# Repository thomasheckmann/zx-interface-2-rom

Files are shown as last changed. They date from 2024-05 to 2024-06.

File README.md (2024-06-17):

# ZX Interface 2 custom multi ROM catridge
Another custom ROM cartridge for ZX Interface 2, supporting 256kb EPROM with manual ROM selection using switch. The 256kb EPROM can hold up to 4 16kb banks, which is selectable with a switch combination.
This cartridge only supports 16KB images and manual bank switch and no paging out - it behaves just as the original ROM catridges.

## Schema and PCB version 1
Just a simple schema created with KiCad from description of original Interface 2 and Roms as found on the internet.

| SCHEMA | PCB |
| --- | --- |
|||

Assembled the cartridge looks like this



## PCB version 1.1
Even that the first version of the PBC works ok, a few errors was made - but again I'm new to KiCad, so I'm slowly learning :-)

- Most important error is that I forgot to check the pads, I simply forgot to check that the pads are added to the solder mask layer! So as can be seen on the image, I had to carefully scrabe the surface - for the pads to be visible.

- The switch are "mirrored" in my oppinion, I would expect the left switch to be the most significant bit (MSB) - so another change for next version.

- Slot in connector turned out to be a bit too narrow, so I had to make it a bit wider.

- If you look closely vias are placed between the connector pads, in next version that will be avoided - by adding safe zones between all pads.

- Resistor value changed from 4K7 to 10K, suggested as the EEPROM is CMOS and not TTL.

- EEPROM rotated so it has same orientation as the other IC (stupid yes, but important to some like me)

- Changed PCB from 4 to 2 layers (Only used 4 to reduces the number of vias created between pads)

With these changes version 1.1 of this little PCB ends up like this:

| <!---> | <!---> |
| --- | --- |
|||

And here how it looks like when build and attached to a ZX Spectrum

| <!---> | <!---> |
| --- | --- |
|||

## How to create image for EEPROM
The W27C512 EEPROM can contain 4 x 16Kb images - selectable with the switch, forming the binary number 0-3 of the bank active.

For Windows
```
COPY /B ROM_3+ROM_2+ROM_1+ROM_0 IMAGE.BIN
```
Use your favorite (E)EPROM programmer to transfer the IMAGE.BIN to the EEPROM

```
LEFT|RIGHT
OFF | OFF - 0: ROM_0
OFF | ON  - 1: ROM_1
ON  | OFF - 2: ROM_2
ON  | ON  - 3: ROM_3
```
## PCB version 1.2
Only small changes to v1.2 of the board, which I think now can be considered final.

- Changed from pull-ups to pull-downs, to match actual behaviour of DIP-SWITCH (up = 1/ON/HIGH, down = 0/OFF/LOW)
- Made PADS 2mm longer, as some connectors might have issues with the smaller size

| SCHEMA | PCB |
| --- | --- |
|||

## How to create image for EEPROM
The W27C512 EEPROM can contain 4 x 16Kb images - selectable with the switch, forming the binary number 0-3 of the bank active.

For Windows
```
COPY /B ROM_0+ROM_1+ROM_2+ROM_3 IMAGE.BIN
```
Use your favorite (E)EPROM programmer to transfer the IMAGE.BIN to the EEPROM
```
LEFT|RIGHT
OFF | OFF - 0: ROM_0
OFF | ON  - 1: ROM_1
ON  | OFF - 2: ROM_2
ON  | ON  - 3: ROM_3
```

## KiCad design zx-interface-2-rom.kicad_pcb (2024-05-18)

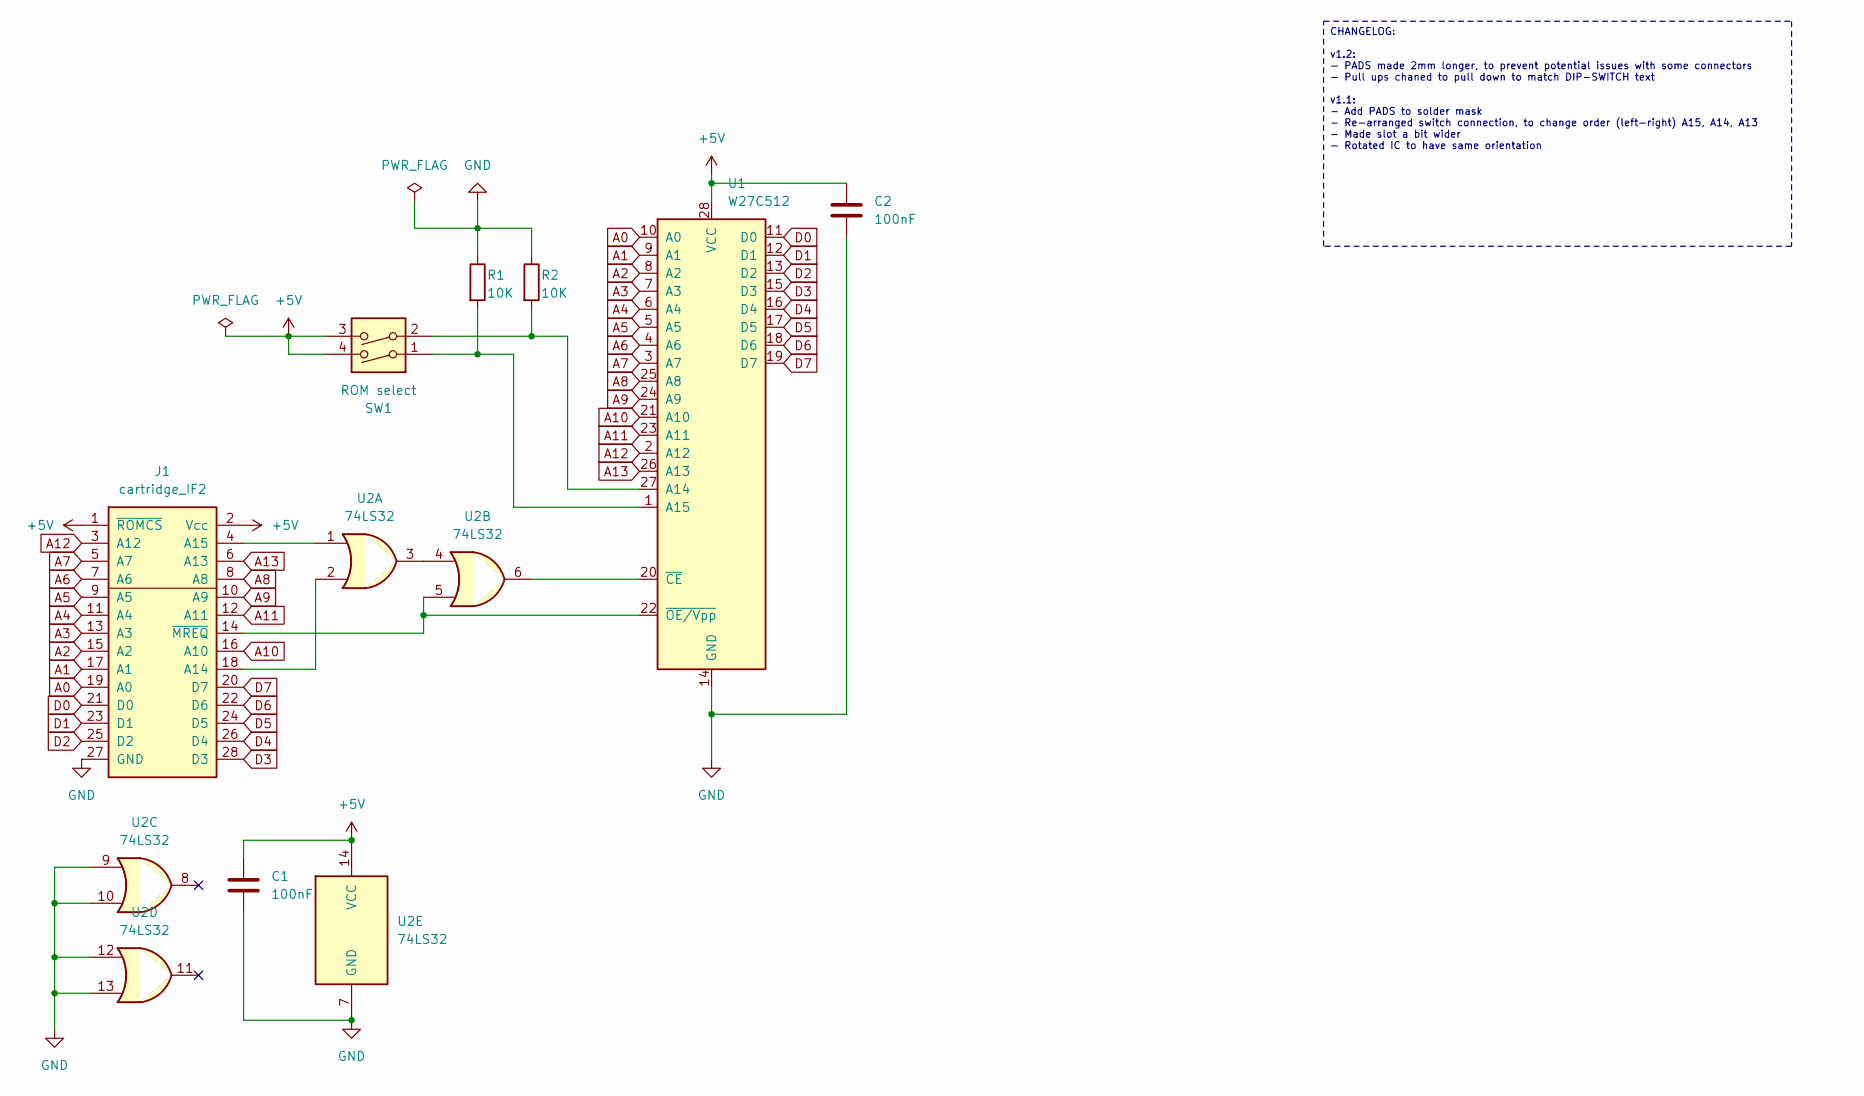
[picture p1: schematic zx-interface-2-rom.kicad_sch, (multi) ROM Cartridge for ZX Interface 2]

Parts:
C1, C2: 100nF; C_Disc_D3.0mm_W1.6mm_P2.50mm
J1: cartridge_IF2; CART_IF2_EDGE
R1, R2: 10K; R_Axial_DIN0207_L6.3mm_D2.5mm_P10.16mm_Horizontal
SW1: ROM select; SW_DIP_SPSTx02_Slide_6.7x6.64mm_W7.62mm_P2.54mm_LowProfile
U1: W27C512; DIP-28_W15.24mm_Socket
U2: 74LS32; DIP-14_W7.62mm_Socket

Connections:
+5V: C1.1, C2.1, J1.1 (~ROMCS), J1.2 (Vcc), SW1.3, SW1.4, U1.28 (VCC), U2.14 (VCC)
A0: J1.19 (A0), U1.10 (A0)
A1: J1.17 (A1), U1.9 (A1)
A2: J1.15 (A2), U1.8 (A2)
A3: J1.13 (A3), U1.7 (A3)
A4: J1.11 (A4), U1.6 (A4)
A5: J1.9 (A5), U1.5 (A5)
A6: J1.7 (A6), U1.4 (A6)
A7: J1.5 (A7), U1.3 (A7)
A8: J1.8 (A8), U1.25 (A8)
A9: J1.10 (A9), U1.24 (A9)
A10: J1.16 (A10), U1.21 (A10)
A11: J1.12 (A11), U1.23 (A11)
A12: J1.3 (A12), U1.2 (A12)
A13: J1.6 (A13), U1.26 (A13)
D0: J1.21 (D0), U1.11 (D0)
D1: J1.23 (D1), U1.12 (D1)
D2: J1.25 (D2), U1.13 (D2)
D3: J1.28 (D3), U1.15 (D3)
D4: J1.26 (D4), U1.16 (D4)
D5: J1.24 (D5), U1.17 (D5)
D6: J1.22 (D6), U1.18 (D6)
D7: J1.20 (D7), U1.19 (D7)
GND: C1.2, C2.2, J1.27 (GND), R1.1, R2.1, U1.14 (GND), U2.7 (GND), U2.9, U2.10, U2.12, U2.13
unnamed: J1.18 (A14), U2.2
unnamed: J1.4 (A15), U2.1
unnamed: J1.14 (~MREQ), U1.22 (~OE/Vpp), U2.5
unnamed: R2.2, SW1.2, U1.27 (A14)
unnamed: R1.2, SW1.1, U1.1 (A15)
unnamed: U1.20 (~CE), U2.6
unnamed: U2.3, U2.4

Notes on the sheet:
CHANGELOG: v1.2: - PADS made 2mm longer, to prevent potential issues with some connectors - Pull ups chaned to pull down to match DIP-SWITCH text v1.1: - Add PADS to solder mask - Re-arranged switch connection, to change order (left-right) A15, A14, A13 - Made slot a bit wider - Rotated IC to have 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

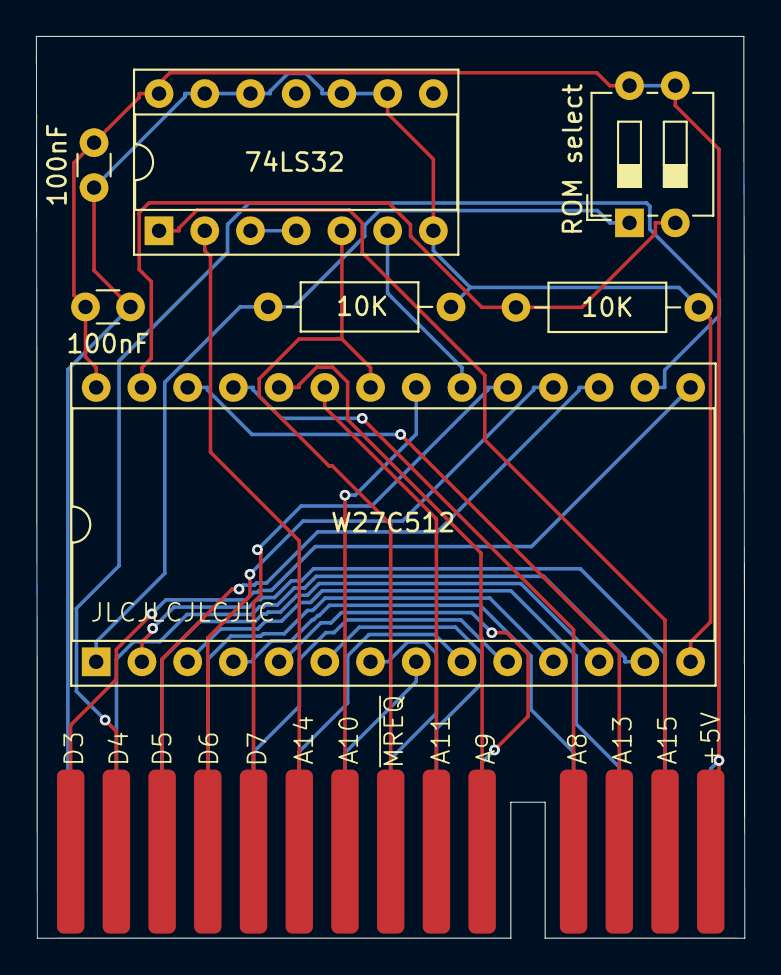
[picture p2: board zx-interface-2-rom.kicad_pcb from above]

Board: 2 copper layers, 39.4 x 50.1 mm, 8 parts (1 on the bottom side), 31 nets.

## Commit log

2024-04-05 Initial version
    [zx-interface-2-rom.kicad_pcb, zx-interface-2-rom.kicad_sch]
2024-04-05 Added Gerbers
    [zx-interface-2-rom-B_Cu.gbr, zx-interface-2-rom-B_Mask.gbr, zx-interface-2-rom-B_Paste.gbr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]
2024-04-08 .gitignore update
    [zx-interface-2-rom.kicad_pcb]
2024-04-14 Updated SYMBOL & FOOTPRINT library
    [zx-interface-2-rom.kicad_pcb, zx-interface-2-rom.kicad_sch]
2024-04-19 version 2 - added solder mask to pad
    [zx-interface-2-rom.kicad_pcb, zx-interface-2-rom.kicad_sch]
2024-04-19 Version 2 - final
    [zx-interface-2-rom-B_Cu.gbr, zx-interface-2-rom-B_Mask.gbr, zx-interface-2-rom-B_Paste.gbr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]
2024-05-18 version 1.2
    [zx-interface-2-rom-B_Cu.gbr, zx-interface-2-rom-B_Mask.gbr, zx-interface-2-rom-B_Paste.gbr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]
